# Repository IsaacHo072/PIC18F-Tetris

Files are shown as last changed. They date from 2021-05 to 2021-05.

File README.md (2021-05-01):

# PIC18F-Tetris
Tetris game which runs on a PIC18

## Hardware
- PIC18F4520
- HT16K33
- 8x8 Bi-Colour Common-Cathode LED Matrix
- 13mm Seven Segment Display, Common-Cathode
- 74HC14
- Some cherry-mx compatible switches

## Program
- Button polling used to read the buttons
- simpletetris.c is the main game program, also directly write to the displays
- Device configuration code in devcon.h

## Tetris
Has basic Tetris features including moving left, right, down and rotating the piece.
Also for holding one Tetris piece in top-left corner. Top-right corner shows the next piece to be dropped.

## Compiling
The program could be compiled with the legacy MPLAB C18 C Complier. 
Change the device configuration and I2C function to I2C1/2 if a different PIC18 microcontroller is used.

## Pictures
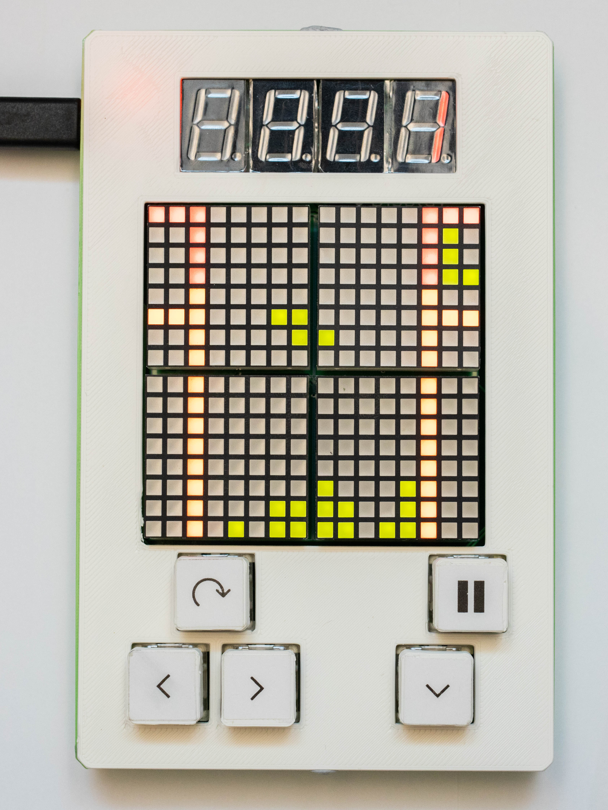
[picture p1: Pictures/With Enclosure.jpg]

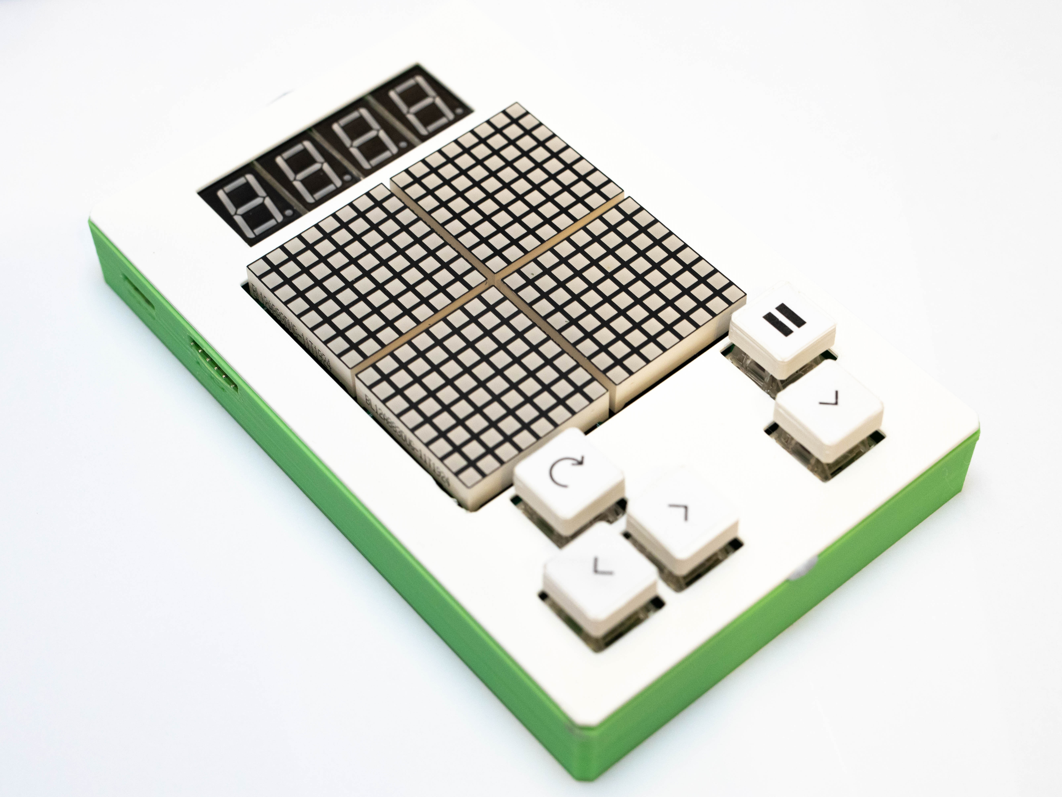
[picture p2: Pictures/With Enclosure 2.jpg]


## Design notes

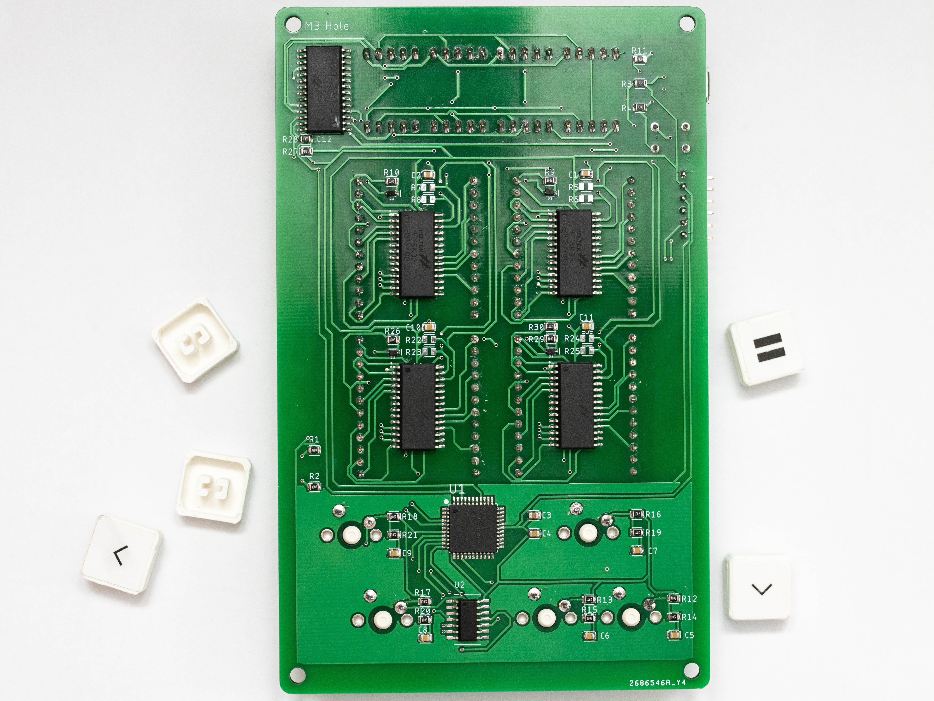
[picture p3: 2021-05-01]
Pictures/PCB - Back.jpg

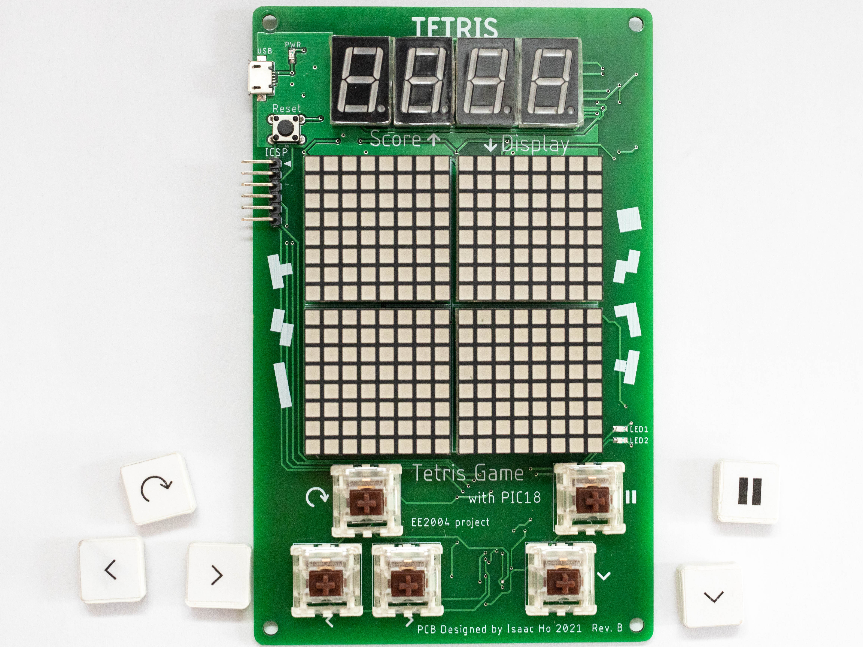
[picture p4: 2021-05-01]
Pictures/PCB - Front.jpg

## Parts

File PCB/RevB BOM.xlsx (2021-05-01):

Bill of Materials
Part | Value | Device | Package | Description | Price - HKD
C1 | 0.1u | C_CHIP-0805 | 0805 | Capacitor | 0.1662
C2 | 0.1u | C_CHIP-0805 | 0805 | Capacitor | 0.1662
C3 | 10u | C_CHIP-0805 | 0805 | Capacitor | 0.2137
C4 | 0.1u | C_CHIP-0805 | 0805 | Capacitor | 0.1662
C5 | 0.1u | C_CHIP-0805 | 0805 | Capacitor | 0.1662
C6 | 0.1u | C_CHIP-0805 | 0805 | Capacitor | 0.1662
C7 | 0.1u | C_CHIP-0805 | 0805 | Capacitor | 0.1662
C8 | 0.1u | C_CHIP-0805 | 0805 | Capacitor | 0.1662
C9 | 0.1u | C_CHIP-0805 | 0805 | Capacitor | 0.1662
C10 | 0.1u | C_CHIP-0805 | 0805 | Capacitor | 0.1662
C11 | 0.1u | C_CHIP-0805 | 0805 | Capacitor | 0.1662
C12 | DNP
D1 | 1A/23V/620mV | DIODE-SCHOTTKY-BAT20J | SOD-323 | Schottky Diode | 0.0865
D2 | 1A/23V/620mV | DIODE-SCHOTTKY-BAT20J | SOD-323 | Schottky Diode | 0.0865
D3 | 1A/23V/620mV | DIODE-SCHOTTKY-BAT20J | SOD-323 | Schottky Diode | 0.0865
D4 | 1A/23V/620mV | DIODE-SCHOTTKY-BAT20J | SOD-323 | Schottky Diode | 0.0865
D5 |  | 7SEG-CK | 7SEG-13 | 7-segment Display | 0.605
D6 |  | 7SEG-CK | 7SEG-13 | 7-segment Display | 0.605
D7 |  | 7SEG-CK | 7SEG-13 | 7-segment Display | 0.605
D8 |  | 7SEG-CK | 7SEG-13 | 7-segment Display | 0.605
IC1 |  | HT16K33-SOP28 | SOIC127P1031X264-28N | RAM Mapping 16*8 LED Controller Driver | 6.41
IC2 |  | HT16K33-SOP28 | SOIC127P1031X264-28N | RAM Mapping 16*8 LED Controller Driver | 6.41
IC3 |  | HT16K33-SOP28 | SOIC127P1031X264-28N | RAM Mapping 16*8 LED Controller Driver | 6.41
IC4 |  | HT16K33-SOP28 | SOIC127P1031X264-28N | RAM Mapping 16*8 LED Controller Driver | 6.41
IC5 |  | HT16K33-SOP28 | SOIC127P1031X264-28N | RAM Mapping 16*8 LED Controller Driver | 6.41
ICSP |  | 1x6 Pin Header | 1x06 | Pin Header | 0.083
LED1 |  | LEDCHIP | 0805 |  | 0.1245
LED2 |  | LEDCHIP | 0805 |  | 0.1295
LED_PWR |  | LEDCHIP | 0805 |  | 0.144
LED4 |  | 8x8 LED Segment | SEGMENT_BICOL_BL-M12A883XX | 8x8 Bi-Color LED Segment Displays: Row = Cathode | 61.82
LED5 |  | 8x8 LED Segment | SEGMENT_BICOL_BL-M12A883XX | 8x8 Bi-Color LED Segment Displays: Row = Cathode | 61.82
LED6 |  | 8x8 LED Segment | SEGMENT_BICOL_BL-M12A883XX | 8x8 Bi-Color LED Segment Displays: Row = Cathode | 61.82
LED7 |  | 8x8 LED Segment | SEGMENT_BICOL_BL-M12A883XX | 8x8 Bi-Color LED Segment Displays: Row = Cathode | 61.82
R1 | 330 | R_0805 | 0805 | Resistor | 0.0413
R2 | 330 | R_0805 | 0805 | Resistor | 0.0413
R3 | 10k | R_0805 | 0805 | Resistor | 0.0413
R4 | 330 | R_0805 | 0805 | Resistor | 0.0413
R5 | DNP
R6 | DNP
R7 | DNP
R8 | DNP
R9 | 10k | R_0805 | 0805 | Resistor | 0.0413
R10 | 10k | R_0805 | 0805 | Resistor | 0.0413
R11 | 330 | R_0805 | 0805 | Resistor | 0.0413
R12 | 10k | R_0805 | 0805 | Resistor | 0.0413
R13 | 10k | R_0805 | 0805 | Resistor | 0.0413
R14 | 10k | R_0805 | 0805 | Resistor | 0.0413
R15 | 10k | R_0805 | 0805 | Resistor | 0.0413
R16 | 10k | R_0805 | 0805 | Resistor | 0.0413
R17 | 10k | R_0805 | 0805 | Resistor | 0.0413
R18 | 10k | R_0805 | 0805 | Resistor | 0.0413
R19 | 10k | R_0805 | 0805 | Resistor | 0.0413
R20 | 10k | R_0805 | 0805 | Resistor | 0.0413
R21 | 10k | R_0805 | 0805 | Resistor | 0.0413
R22 | DNP
R23 | DNP
R24 | DNP
R25 | DNP
R26 | 10K | R_0805 | 0805 | Resistor | 0.0413
R27 | 4.7K | R_0805 | 0805 | Resistor | 0.0413
R28 | 4.7K | R_0805 | 0805 | Resistor | 0.0413
R29 | 10K | R_0805 | 0805 | Resistor | 0.0413
R30 | 10K | R_0805 | 0805 | Resistor | 0.0413
S1 |  | SPST Switch 6mm | TACTILE_SWITCH_PTH_6.0MM | Push Button | 0.0498
SWITCH1 |  | Cherry MX Switch |  | Cherry MX Series Keyswitch | 1.163
SWITCH2 |  | Cherry MX Switch |  | Cherry MX Series Keyswitch | 1.163
SWITCH3 |  | Cherry MX Switch |  | Cherry MX Series Keyswitch | 1.163
SWITCH4 |  | Cherry MX Switch |  | Cherry MX Series Keyswitch | 1.163
SWITCH5 |  | Cherry MX Switch |  | Cherry MX Series Keyswitch | 1.163
U1 |  | PIC18F4520-I/PT | QFP80P1200X1200X120-44N | Flash Microcontrollers | 15.42
U2 |  | SN74HC14NSR | SOP127P780X200-14N | Hex Schmitt-Trigger Inverters | 1.062
USB |  | USB3085-XX-X_RevD | GCT_USB3085-XX-X_REVD | Micro USB Receptacle, Type AB, Surface Mount, Horizontak, Bottom Mount, Without Peg | 0.498
 | PCB |  |  |  | 22.956
 |  |  |  | Total | 331.1621

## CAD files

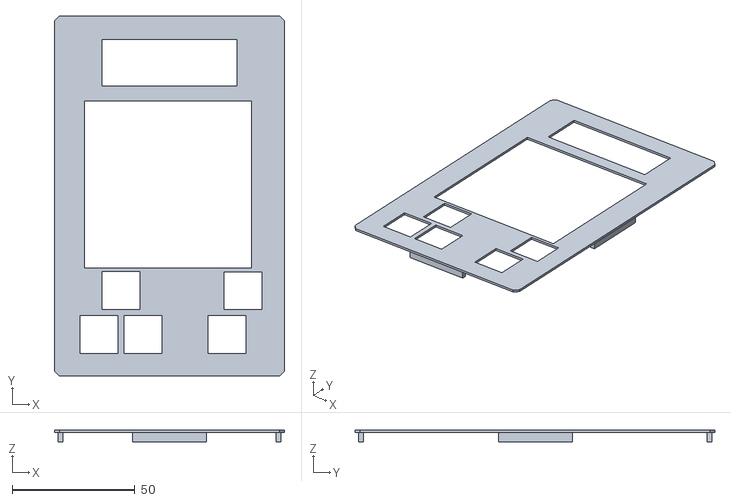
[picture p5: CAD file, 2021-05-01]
Enclosure/cover.stl
93.5 x 146.4 x 5.00

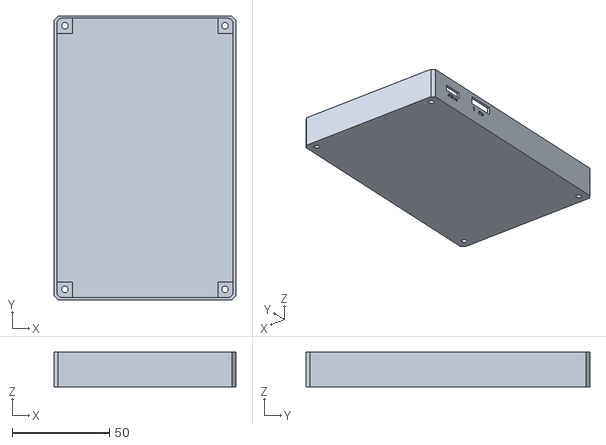
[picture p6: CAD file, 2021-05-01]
Enclosure/base.stl
93.5 x 146.4 x 18.0

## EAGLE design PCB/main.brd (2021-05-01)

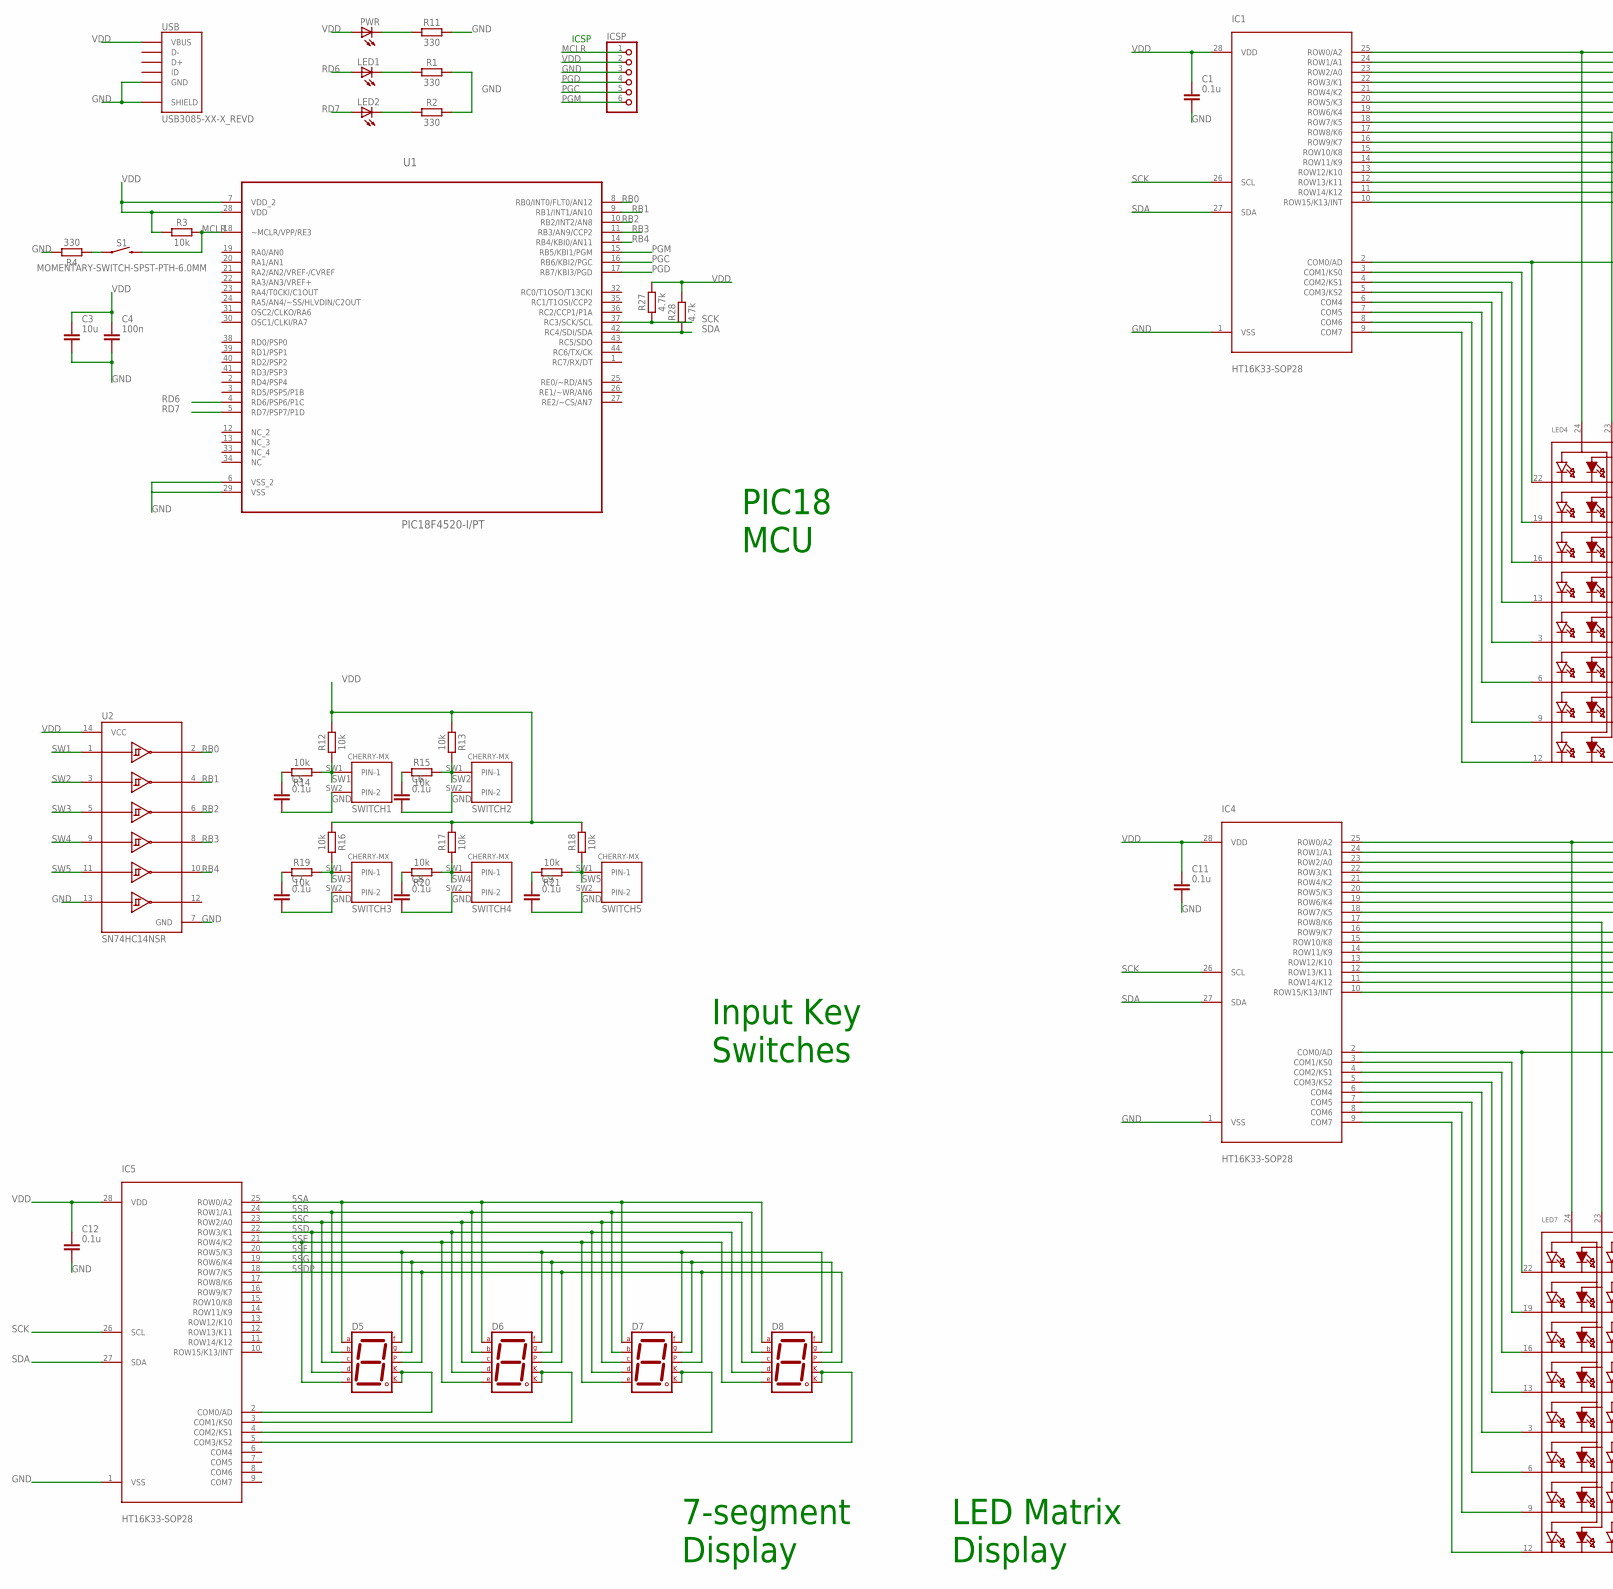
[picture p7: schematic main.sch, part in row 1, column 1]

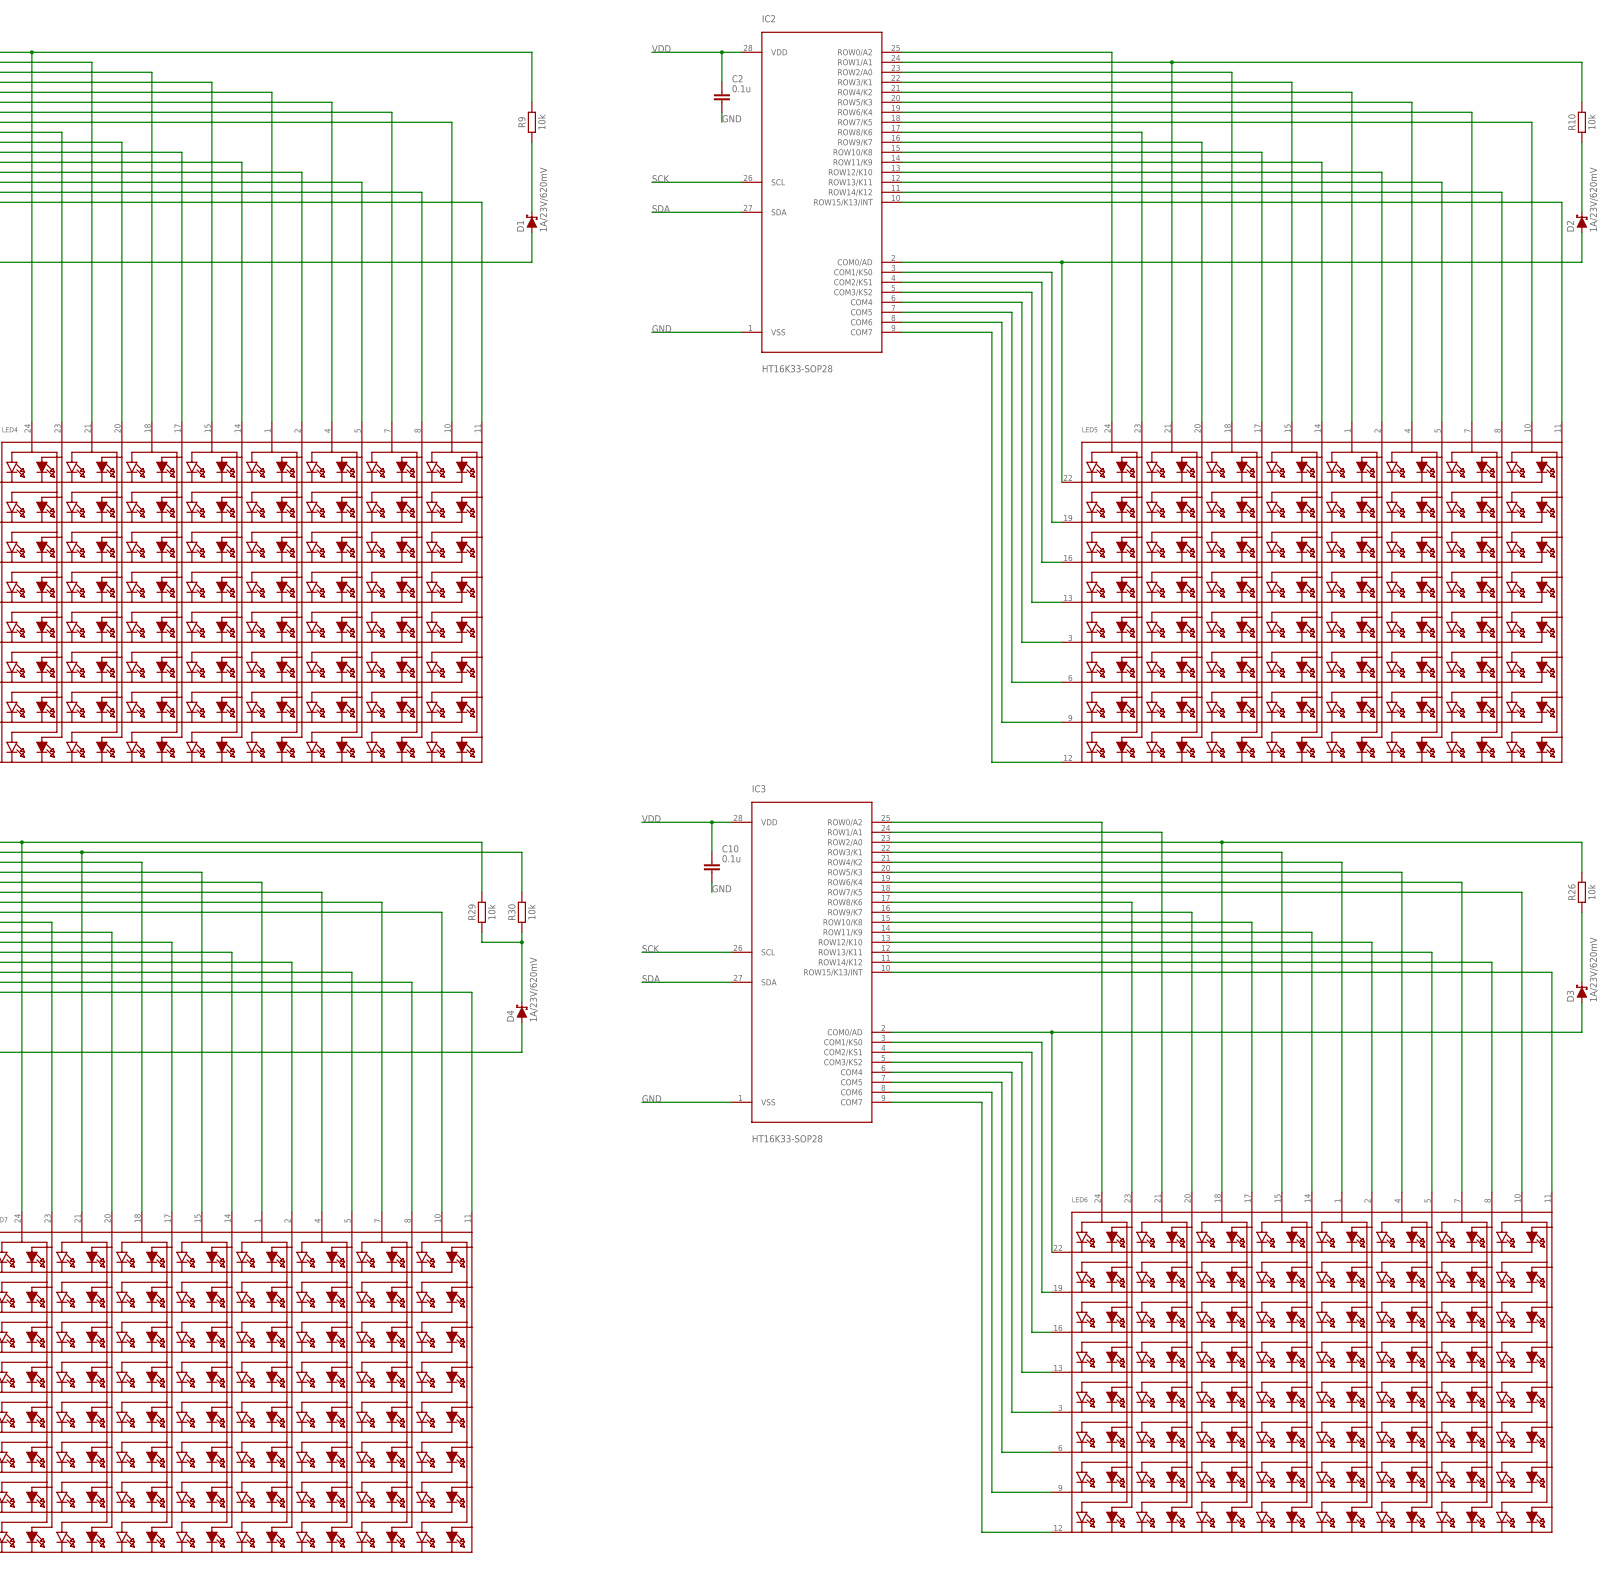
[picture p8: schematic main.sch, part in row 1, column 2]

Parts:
C1, C2, C5, C6, C7, C8, C9, C10, C11, C12: 0.1u; CAPC2012X110
C3: 10u; CAPC2012X110
C4: 100n; CAPC2012X110
D1, D2, D3, D4: 1A/23V/620mV; SOD-323
D5, D6, D7, D8: 7SEG-CK; 7SEG-13
IC1, IC2, IC3, IC4, IC5: HT16K33-SOP28; SOIC127P1031X264-28N
ICSP: PINHD-1X6; 1X06
LED1, LED2: LEDCHIPLED_0805; CHIPLED_0805
LED4, LED5, LED6, LED7: SEGMENT_8X8_BICOLOR_ROWCATHODEMI2A883XX; SEGMENT_BICOL_BL-M12A883XX
PWR: LEDCHIPLED_0805; CHIPLED_0805
R1, R2, R4, R11: 330; RESC2012X65
R3, R9, R10, R12, R13, R14, R15, R16, R17, R18, R19, R20, R21, R26, R29, R30: 10k; RESC2012X65
R27, R28: 4.7k; RESC2012X65
S1: MOMENTARY-SWITCH-SPST-PTH-6.0MM; TACTILE_SWITCH_PTH_6.0MM
SWITCH1, SWITCH2, SWITCH3, SWITCH4, SWITCH5: CHERRY-MX
U1: PIC18F4520-I/PT; QFP80P1200X1200X120-44N
U2: SN74HC14NSR; SOP127P780X200-14N
USB: USB3085-XX-X_REVD; GCT_USB3085-XX-X_REVD

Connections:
5D2: D7.3 (CK1), D7.8 (CK2), IC5.4 (COM2/KS1)
5D3: D8.3 (CK1), D8.8 (CK2), IC5.5 (COM3/KS2)
5SA: D5.7 (A), D6.7 (A), D7.7 (A), D8.7 (A), IC5.25 (ROW0/A2)
5SB: D5.6 (B), D6.6 (B), D7.6 (B), D8.6 (B), IC5.24 (ROW1/A1)
5SC: D5.4 (C), D6.4 (C), D7.4 (C), D8.4 (C), IC5.23 (ROW2/A0)
5SD: D5.2 (D), D6.2 (D), D7.2 (D), D8.2 (D), IC5.22 (ROW3/K1)
5SDP: D5.5 (DP), D6.5 (DP), D7.5 (DP), D8.5 (DP), IC5.18 (ROW7/K5)
5SE: D5.1 (E), D6.1 (E), D7.1 (E), D8.1 (E), IC5.21 (ROW4/K2)
5SF: D5.9 (F), D6.9 (F), D7.9 (F), D8.9 (F), IC5.20 (ROW5/K3)
5SG: D5.10 (G), D6.10 (G), D7.10 (G), D8.10 (G), IC5.19 (ROW6/K4)
GND: C1.2, C2.2, C3.2, C4.2, C5.2, C6.2, C7.2, C8.2, C9.2, C10.2, C11.2, C12.2, IC1.1 (VSS), IC2.1 (VSS), IC3.1 (VSS), IC4.1 (VSS), IC5.1 (VSS), ICSP.3, R1.2, R2.2, R4.2, R11.1, SWITCH1.SW2 (PIN-2), SWITCH2.SW2 (PIN-2), SWITCH3.SW2 (PIN-2), SWITCH4.SW2 (PIN-2), SWITCH5.SW2 (PIN-2), U1.6 (VSS_2), U1.29 (VSS), U2.7 (GND), U2.13 (6A), USB.5 (GND), USB.6 (SHIELD), USB.7 (SHIELD), USB.8 (SHIELD), USB.9 (SHIELD)
MCLR: ICSP.1, R3.2, S1.3 (2), U1.18 (~MCLR/VPP/RE3)
unnamed: IC1.25 (ROW0/A2), LED4.24 (A1), R9.2
unnamed: IC1.24 (ROW1/A1), LED4.21 (A3)
unnamed: R4.1, S1.1
unnamed: IC1.23 (ROW2/A0), LED4.18 (A5)
unnamed: IC1.22 (ROW3/K1), LED4.15 (A7)
unnamed: IC1.21 (ROW4/K2), LED4.1 (A9)
unnamed: IC1.20 (ROW5/K3), LED4.4 (A11)
unnamed: IC1.19 (ROW6/K4), LED4.7 (A13)
unnamed: IC1.18 (ROW7/K5), LED4.10 (A15)
unnamed: IC1.17 (ROW8/K6), LED4.23 (A2)
unnamed: IC1.16 (ROW9/K7), LED4.20 (A4)
unnamed: IC1.15 (ROW10/K8), LED4.17 (A6)
unnamed: IC1.14 (ROW11/K9), LED4.14 (A8)
unnamed: IC1.13 (ROW12/K10), LED4.2 (A10)
unnamed: IC1.12 (ROW13/K11), LED4.5 (A12)
unnamed: IC1.11 (ROW14/K12), LED4.8 (A14)
unnamed: IC1.10 (ROW15/K13/INT), LED4.11 (A16)
unnamed: D1.A, IC1.2 (COM0/AD), LED4.22 (K1)
unnamed: IC1.3 (COM1/KS0), LED4.19 (K2)
unnamed: IC1.4 (COM2/KS1), LED4.16 (K3)
unnamed: IC1.5 (COM3/KS2), LED4.13 (K4)
unnamed: IC1.6 (COM4), LED4.3 (K5)
unnamed: IC1.7 (COM5), LED4.6 (K6)
unnamed: IC1.8 (COM6), LED4.9 (K7)
unnamed: IC1.9 (COM7), LED4.12 (K8)
unnamed: D1.C, R9.1
unnamed: C9.1, R21.2
unnamed: IC2.25 (ROW0/A2), LED5.24 (A1)
unnamed: IC2.24 (ROW1/A1), LED5.21 (A3), R10.2
unnamed: IC2.23 (ROW2/A0), LED5.18 (A5)
unnamed: IC2.22 (ROW3/K1), LED5.15 (A7)
unnamed: IC2.21 (ROW4/K2), LED5.1 (A9)
unnamed: IC2.20 (ROW5/K3), LED5.4 (A11)
unnamed: IC2.19 (ROW6/K4), LED5.7 (A13)
unnamed: IC2.18 (ROW7/K5), LED5.10 (A15)
unnamed: IC2.17 (ROW8/K6), LED5.23 (A2)
unnamed: IC2.16 (ROW9/K7), LED5.20 (A4)
unnamed: IC2.15 (ROW10/K8), LED5.17 (A6)
unnamed: IC2.14 (ROW11/K9), LED5.14 (A8)
unnamed: IC2.13 (ROW12/K10), LED5.2 (A10)
unnamed: IC2.12 (ROW13/K11), LED5.5 (A12)
unnamed: IC2.11 (ROW14/K12), LED5.8 (A14)
unnamed: IC2.10 (ROW15/K13/INT), LED5.11 (A16)
unnamed: D2.A, IC2.2 (COM0/AD), LED5.22 (K1)
unnamed: IC2.3 (COM1/KS0), LED5.19 (K2)
unnamed: IC2.4 (COM2/KS1), LED5.16 (K3)
unnamed: LED1.C, R1.1
unnamed: PWR.C, R11.2
unnamed: IC2.5 (COM3/KS2), LED5.13 (K4)
unnamed: IC2.6 (COM4), LED5.3 (K5)
unnamed: IC2.7 (COM5), LED5.6 (K6)
unnamed: IC2.8 (COM6), LED5.9 (K7)
unnamed: LED2.C, R2.1
unnamed: C5.1, R14.2
unnamed: C6.1, R15.1
unnamed: C8.1, R20.2
unnamed: C7.1, R19.1
unnamed: IC2.9 (COM7), LED5.12 (K8)
unnamed: D2.C, R10.1
unnamed: IC4.24 (ROW1/A1), LED7.21 (A3), R30.2
unnamed: IC4.23 (ROW2/A0), LED7.18 (A5)
unnamed: IC4.22 (ROW3/K1), LED7.15 (A7)
unnamed: IC4.21 (ROW4/K2), LED7.1 (A9)
unnamed: IC4.20 (ROW5/K3), LED7.4 (A11)
unnamed: IC4.19 (ROW6/K4), LED7.7 (A13)
unnamed: IC4.18 (ROW7/K5), LED7.10 (A15)
unnamed: IC4.17 (ROW8/K6), LED7.23 (A2)
unnamed: IC4.16 (ROW9/K7), LED7.20 (A4)
unnamed: IC4.15 (ROW10/K8), LED7.17 (A6)
unnamed: IC4.14 (ROW11/K9), LED7.14 (A8)
unnamed: IC4.13 (ROW12/K10), LED7.2 (A10)
unnamed: IC4.12 (ROW13/K11), LED7.5 (A12)
unnamed: IC4.11 (ROW14/K12), LED7.8 (A14)
unnamed: IC4.10 (ROW15/K13/INT), LED7.11 (A16)
unnamed: D4.A, IC4.2 (COM0/AD), LED7.22 (K1)
unnamed: IC4.3 (COM1/KS0), LED7.19 (K2)
unnamed: IC4.4 (COM2/KS1), LED7.16 (K3)
unnamed: IC4.5 (COM3/KS2), LED7.13 (K4)
unnamed: IC4.6 (COM4), LED7.3 (K5)
unnamed: IC4.7 (COM5), LED7.6 (K6)
unnamed: IC4.8 (COM6), LED7.9 (K7)
unnamed: IC4.9 (COM7), LED7.12 (K8)
unnamed: D4.C, R29.1, R30.1
unnamed: IC4.25 (ROW0/A2), LED7.24 (A1), R29.2
unnamed: IC3.25 (ROW0/A2), LED6.24 (A1)
unnamed: IC3.24 (ROW1/A1), LED6.21 (A3)
unnamed: IC3.23 (ROW2/A0), LED6.18 (A5), R26.2
unnamed: IC3.22 (ROW3/K1), LED6.15 (A7)
unnamed: IC3.21 (ROW4/K2), LED6.1 (A9)
unnamed: IC3.20 (ROW5/K3), LED6.4 (A11)
unnamed: IC3.19 (ROW6/K4), LED6.7 (A13)
unnamed: IC3.18 (ROW7/K5), LED6.10 (A15)
unnamed: IC3.17 (ROW8/K6), LED6.23 (A2)
unnamed: IC3.16 (ROW9/K7), LED6.20 (A4)
unnamed: IC3.15 (ROW10/K8), LED6.17 (A6)
unnamed: IC3.14 (ROW11/K9), LED6.14 (A8)
unnamed: IC3.13 (ROW12/K10), LED6.2 (A10)
unnamed: IC3.12 (ROW13/K11), LED6.5 (A12)
unnamed: IC3.11 (ROW14/K12), LED6.8 (A14)
unnamed: IC3.10 (ROW15/K13/INT), LED6.11 (A16)
unnamed: D3.A, IC3.2 (COM0/AD), LED6.22 (K1)
unnamed: IC3.3 (COM1/KS0), LED6.19 (K2)
unnamed: IC3.4 (COM2/KS1), LED6.16 (K3)
unnamed: IC3.5 (COM3/KS2), LED6.13 (K4)
unnamed: IC3.6 (COM4), LED6.3 (K5)
unnamed: IC3.7 (COM5), LED6.6 (K6)
unnamed: IC3.8 (COM6), LED6.9 (K7)
unnamed: IC3.9 (COM7), LED6.12 (K8)
unnamed: D3.C, R26.1
unnamed: D5.3 (CK1), D5.8 (CK2), IC5.2 (COM0/AD)
unnamed: D6.3 (CK1), D6.8 (CK2), IC5.3 (COM1/KS0)
PGC: ICSP.5, U1.16 (RB6/KBI2/PGC)
PGD: ICSP.4, U1.17 (RB7/KBI3/PGD)
PGM: ICSP.6, U1.15 (RB5/KBI1/PGM)
RB0: U1.8 (RB0/INT0/FLT0/AN12), U2.2 (1Y)
RB1: U1.9 (RB1/INT1/AN10), U2.4 (2Y)
RB2: U1.10 (RB2/INT2/AN8), U2.6 (3Y)
RB3: U1.11 (RB3/AN9/CCP2), U2.8 (4Y)
RB4: U1.14 (RB4/KBI0/AN11), U2.10 (5Y)
RD6: LED1.A, U1.4 (RD6/PSP6/P1C)
RD7: LED2.A, U1.5 (RD7/PSP7/P1D)
SCK: IC1.26 (SCL), IC2.26 (SCL), IC3.26 (SCL), IC4.26 (SCL), IC5.26 (SCL), R27.2, U1.37 (RC3/SCK/SCL)
SDA: IC1.27 (SDA), IC2.27 (SDA), IC3.27 (SDA), IC4.27 (SDA), IC5.27 (SDA), R28.2, U1.42 (RC4/SDI/SDA)
SW1: R12.1, R14.1, SWITCH1.SW1 (PIN-1), U2.1 (1A)
SW2: R13.2, R15.2, SWITCH2.SW1 (PIN-1), U2.3 (2A)
SW3: R16.2, R19.2, SWITCH3.SW1 (PIN-1), U2.5 (3A)
SW4: R17.1, R20.1, SWITCH4.SW1 (PIN-1), U2.9 (4A)
SW5: R18.1, R21.1, SWITCH5.SW1 (PIN-1), U2.11 (5A)
VDD: C1.1, C2.1, C3.1, C4.1, C10.1, C11.1, C12.1, IC1.28 (VDD), IC2.28 (VDD), IC3.28 (VDD), IC4.28 (VDD), IC5.28 (VDD), ICSP.2, PWR.A, R3.1, R12.2, R13.1, R16.1, R17.2, R18.2, R27.1, R28.1, U1.7 (VDD_2), U1.28 (VDD), U2.14 (VCC), USB.1 (VBUS)

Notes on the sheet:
ICSP
PIC18 MCU
Input Key Switches
7-segment Display
LED Matrix Display

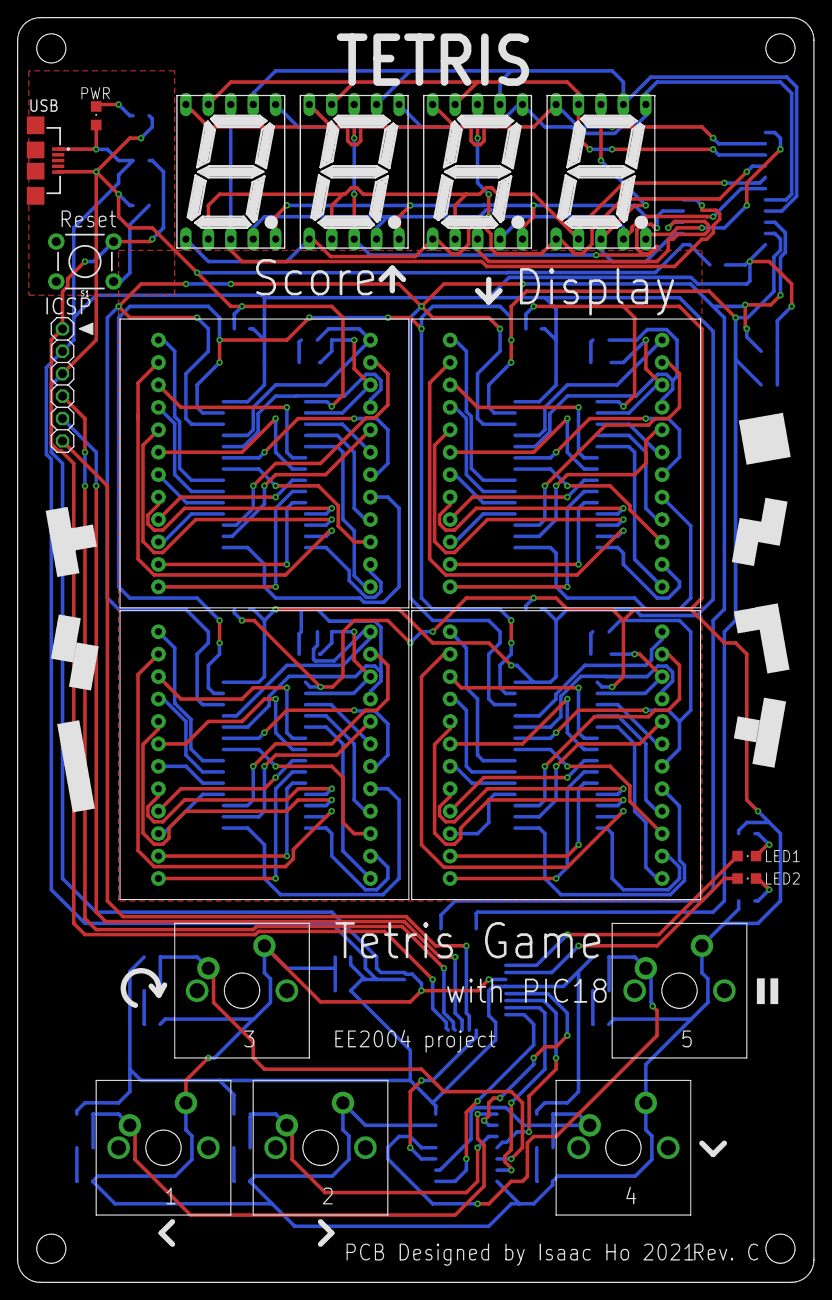
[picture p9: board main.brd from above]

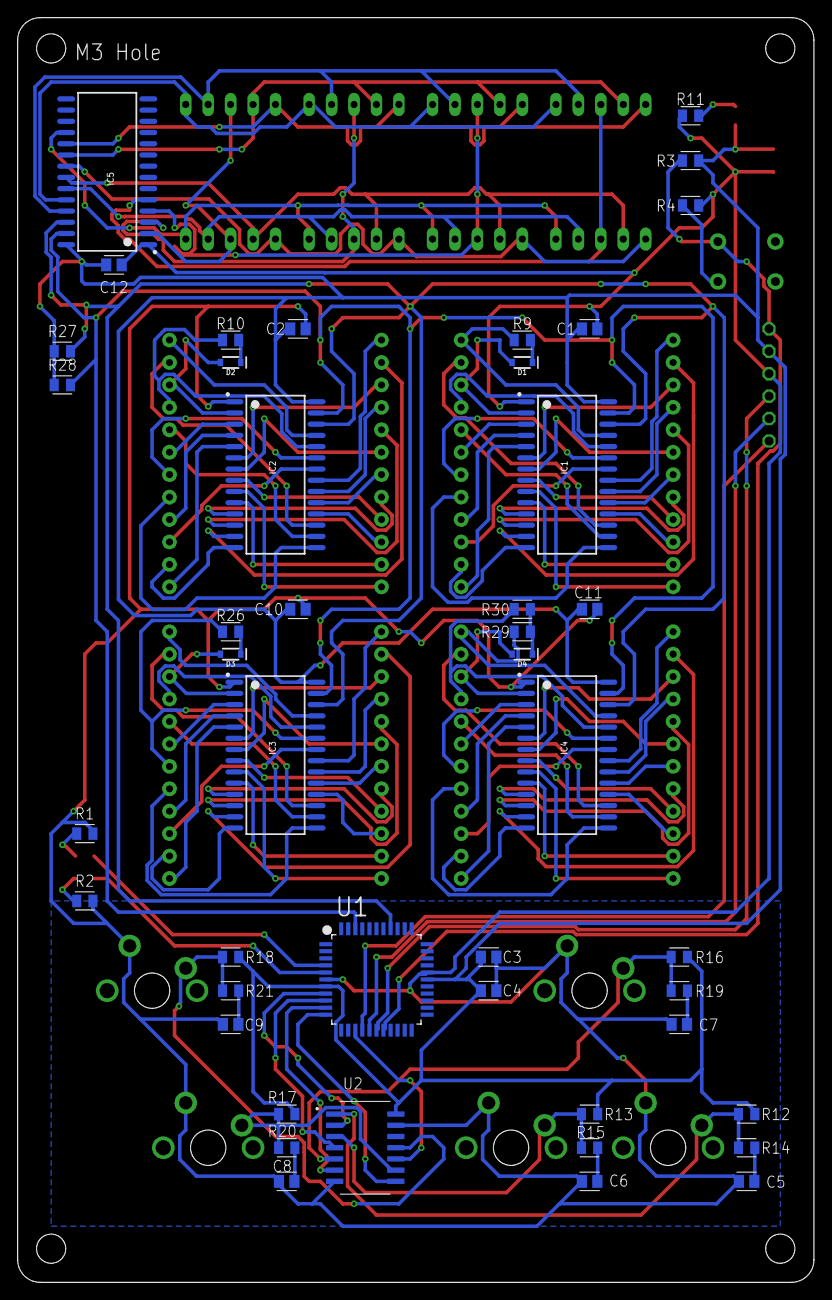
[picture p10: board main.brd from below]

Board: 2 copper layers, 90.2 x 143.2 mm, 64 parts (45 on the bottom side), 141 nets.

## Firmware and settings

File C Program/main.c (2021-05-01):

#include <p18F4520.h>

#include "devcon.h"

static unsigned char buttonDisable = 0;

void main(void){

	DeviceSetup();
	Delay1KTCYx(4);	//wait 1ms for display controllers to turn on
	OpenI2C(MASTER,SLEW_OFF);
	InitializeDisplay(); 
	ClearDisplay();
	StartTetris();
	Delay10KTCYx(10);
	DropTetris();

	while(1) {	
		while (isGameover() == 0) {
			if (ButtonLeft == 1 && buttonDisable == 0){
				MoveTetris(1);
				LED2 = 1;
				buttonDisable = 1;
			} else if (ButtonRight == 1 && buttonDisable == 0){
				MoveTetris(2);
				LED2 = 1;
				buttonDisable = 1;			
			} else if (ButtonRotate == 1 && buttonDisable == 0){	
				RotateTetris();
				LED2 = 1;
				buttonDisable = 1;
			} else if (ButtonDown == 1){
				MoveTetris(3);
				Delay10KTCYx(10);
			} else if (ButtonHold == 1){
				HoldTetris();
				Delay10KTCYx(10);
			}
			
			if (ButtonLeft == 0 && ButtonRight == 0 && ButtonRotate == 0) {
				LED2 = 0;
				buttonDisable = 0;
			}

			if (ReadTimer0() >= 32767){
				OpenTimer0(T0_16BIT & T0_SOURCE_INT & T0_PS_1_256);
				WriteTimer0(24954);
				MoveTetris(3);
				WriteNumber(getScore());
			}
		}

		while (isGameover() == 1) {
			if (ButtonHold == 1){
				reset();
				ClearDisplay();		
				StartTetris();
				Delay10KTCYx(100);
				DropTetris();
			}
		}	
	}
}

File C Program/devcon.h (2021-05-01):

#ifndef DEVCON
#define DEVCON

#include <stdlib.h>
#include <math.h>
#include <i2c.h>
#include <delays.h>
#include <timers.h>

#include "simpletetris.h"
#include "ht16k33.h"
#include "helper.h"

#pragma config OSC = INTIO67
#pragma config WDT = OFF
#pragma config LVP = ON
#pragma config PBADEN = OFF

//LED1, LED2
#define LED1 PORTDbits.RD6
#define LED2 PORTDbits.RD7
//Buttons
#define ButtonLeft PORTBbits.RB0
#define ButtonRight PORTBbits.RB1
#define ButtonRotate PORTBbits.RB2
#define ButtonDown PORTBbits.RB3
#define ButtonHold PORTBbits.RB4


void DeviceSetup(void)
{
	//Use Internal Oscillator at 8MHz
	OSCCON = 0x72;
	OSCTUNE = 0x00;
	SSPADD = 0x04;

	//Ports Setup
	LATA = 0x00;
	LATB = 0x00;
	LATC = 0x00;
	LATD = 0x00;
	
	TRISA = 0xFF;
	TRISB = 0xFF;
	TRISC = 0xFF;
	TRISD = 0x3F;
	
	//Timer for 1s (around 1s)
	OpenTimer0(T0_16BIT & T0_SOURCE_INT & T0_PS_1_256);
	WriteTimer0(24954);
}

#endif

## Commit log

2021-05-01 Add PCB files
    [main.brd, main.sch]
2021-05-01 add pictures and enclosure
2021-05-01 Added STL files
    [base.stl, cover.stl]
2021-05-01 Added BOM
    [RevB BOM.xlsx]

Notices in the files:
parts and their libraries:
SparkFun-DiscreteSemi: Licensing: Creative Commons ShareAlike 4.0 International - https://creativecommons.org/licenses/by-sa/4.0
